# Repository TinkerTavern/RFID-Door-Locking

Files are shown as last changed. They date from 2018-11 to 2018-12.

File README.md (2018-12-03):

# RFID-Door-Locking
## Year 1 Semester 1 Coursework 2: An RFID Door lock with facial detection

This coursework involved only one main task: To create a program that uses 2 Arduinos communicating
together in some way.

With this, we decided to create an RFID door locking system, that uses facial detection to trigger.

This works by:
1) Using a python program, linked to OpenCV to detect a face in a live feed of a webcam
2) Once a face is detected, a serial command is sent to the master Arduino, to start the code
3) When the code starts, a 30 second timer starts, and the user is asked to scan a valid RFID tag
4) If the user scans a valid tag, the user is then asked to answer a question (the answer being 00101010, 42 in binary)
5) If they enter that correctly and in sufficient time, then the "door" is unlocked, and a noise is made

The RFID tags and question answers are sent to a slave Arduino, which then checks to see if it's valid, and sends that back
If the user enters 3 incorrect passwords; scans an invalid card 3 times; or doesn't finish the tasks in time, the user will be
locked out and an alarm will go off.

All of the information is shown on a small TFT screen, controlled by the master Arduino
This information includes the timer and the text telling the user what to do

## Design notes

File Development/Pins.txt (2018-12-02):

0/1- USB Comms (reserved)
2/3- BT Comms
4-
5- Buzzer
6-8- TFT Screen
9-13- RFID Reader
A0-A2- Buttons
A4/A5- LED's

ICSP Pins
3/4- Screen

~ Red: 3/5V
~ Black: GND
~ Orange: RX/TX Comms
~ Blue: RFID Scanner
~ Yellow: MSI
~ Gray: MSO
~ Green: Screen
~ White: Piezo, Buttons and Bubble Boi

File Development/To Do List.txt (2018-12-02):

## To Do List ##

~ Change question to "What is the answer to the universe" (42 in binary); J DONE
~ Get a timer working (possibly show on the screen); J DONE
~ Get face detection to link to arduino; T DONE
~ Reset program on win; TJ DONE
~ Get bubble boi to work; T 
~ Function for LCD Screen output (removing duplicate code); J DONE? Could be better
~ Clean code; TJ
~ Add new mode to slave for question mode; J DONE
~ Make the master play a tune when door unlocked; T DONE
~ Make an alarm when timer runs out/incorrect entry; T DONE
~ Fix the button bouncing issues (boolean); J

~ Documentation;
~ Video;

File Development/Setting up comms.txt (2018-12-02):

Slave Arduino:
	To start connect
	5v ---> EN
	Rx ---> Rx
	Tx ---> Tx
	Send empty sketch to arduino (with Rx/Tx disconnected)
	As arduino starts up hold button on side of arduino
	Open Serial monitor at 38400 Baud and both NL & CR
Commands Sent:
	AT + UART --- this should show 38400
	AT + ROLE? --- this should show 0
	AT + ADDR? -- should give an address, save this for master

Master Arduino:
	To start connect
	5v ---> EN
	Rx ---> Rx
	Tx ---> Tx
	Send empty sketch to arduino (with Rx/Tx disconnected)
	As arduino starts up hold button on side of arduino
	Open Serial monitor at 38400 Baud and both NL & CR
Commands Sent:
	AT + UART --- this should show 38400
	AT + ROLE = 1 --- this should show "ok" and will set it to master
	AT + CMODE = 0 --- connect mode to fixed address
	AT + BIND = Address --- address seperated by commas not colons
				this is attaching the address to be connected to 

now when done disconnect 5v ---> EN 
			 connect RX and TX on module to pins you want on arduino

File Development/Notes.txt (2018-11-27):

Face Detection:
- 

+ A little faster (if needed)

Arduino-PC Comms:
- Read the actual data
- 

+ If we want, we can use HM 10 modules for extra comms with PC and phones
+

LED Matrix:
- Points to current focus (camera, tag or questions)
- If wrong, X mark, happy face if right

Documentation:
- Write about the sections you do AS YOU GO ALONG (but not in big detail) 
- References
-

Features:
- Face Detection
- Arduino-PC Comms
- Arduino-Arduino comms
- RFID Scanner
- LED Matrix
- Screen and buttons (maybe numpad)
- Speakers (synchronised)

Potential problems:
- Not enough pins
- Comms issues

Questions:
- What happens when the user enters a wrong answer or wrong tag.

Camera first
Then Tag
Then Question

We thouhgt we wouldn't have enough pins for our project, however some research (LINK), shows that the analogue in pins can in fact be used
We thought about using a shift register for other components.. thoughts later

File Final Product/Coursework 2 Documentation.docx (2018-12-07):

# Overview

Our project is a prototype for a high-security RFID door lock system that would be used in an area where multi factor authentication (e.g. government building). The program involves 2 Arduinos, a master and a slave. The master runs all the hardware components, including an RFID scanner, 2 buttons, a piezo speaker, a screen and a servo (to represent the door lock mechanism). The slave Arduino controls the security and has no hardware components. They’re both connected through Bluetooth serial, using HC-05 modules.

# Software

Face Detection: For the prototype, we’ve decided to go with facial detection, as it is significantly easier to implement, given the time constraints. In order to do this, we’ve created a python 3 program using a library called Open CV. This has inbuilt face detection algorithms. Of which we’ve decided to use the HAAR algorithm (Cascade).

PC-Arduino Comms: In order for the face detection to be linked with the Arduino, the python program must send a serial command to the master Arduino. This is done using a library called PySerial, and allows for the main program to be run only when a face has been detected for long enough

Master Program: The master program controls the majority of the components used in the system, including the RFID scanner, the TFT screen, the buttons, and the “door lock”, which is a servo in the prototype.

Master-Slave Comms: The master must communicate with the slave every time an rfid tag is scanned, or a password is entered. This is then checked with the correct/expected output(s), and another signal is sent back to the master.

Slave Program: The slave is mostly checking the expected outputs against the actual outputs. However, it’s also in charge of controlling the bubble machine whenever the timer runs out, or they get 3 passwords or RFID tags wrong

# Hardware

PC: The computer simply needs python 3.X with the previously mentioned libraries installed, as well as a webcam, and a spare USB port to plug the master in to. In a final version of this program, the PC-Arduino coms might be done through Bluetooth/another wireless communication protocol

Master: The master contains: An [Name] RFID receiver; a TFT screen; 2 buttons; a piezo speaker; a 9g servo and a HC-05 Bluetooth module in master mode. In a final version of this system, a pin pad would replace the buttons, so the pin can be harder to crack (> 256 options)

Slave: The slave contains: A [Name] relay connected to a bubble machine and a HC-05 Bluetooth module in slave mode. In a final version of this system, the bubble machine would be replaced with something higher security, such as a taser

Communications: We decided to go for a Bluetooth serial connection between the two Arduinos, because in the final version of this system, one of the modules would be in a different area. This would probably use WiFi/ethernet, however using this for our prototype would have been a challenge due to issues regarding the network used on campus. Using Bluetooth also made development of the project easier, as the Arduinos didn’t need to be right next to each other while testing and developing features

# Difficulties

PC-Arduino Coms: The main issue we had here was involving the fact that we couldn’t see the serial display for the master Arduino while the python program was communicating with it.

Master-Slave Coms: The main issue we had when it came to getting the Arduinos to communicate was setting up and connecting the two HC-05 modules together. Once they were together, the process of using them was the same as typical serial if they were wired together

Connecting the TFT Screen and RFID Reader Simultaniously: When we were trying to connect the two devices to the master at the slave time, we noticed that some of the pins on each device can’t be reassigned using code (MOSI, MISO and [Insert]) pins were preassigned and need to be used in order for the device to function. After some research, we found out that the 6 female [NAME] pins on the Arduino board can be used as secondary pins for such features. Therefore all we needed to do was plug them into there.

Fritzing Schematic: While making the schematic, we ended up not having all of the components we used in our system available for use. On top of this, the 6 female [NAME] pins that we had to use weren’t available on the Arduino schematic on the program. This meant building the schematic was more challenging, as we had to “build” our own schematics for each of the new components

Connecting the Bubble Machine: Due to the bubble machine being an off the shelf product, it wasn’t inherently designed to work with the Arduino. This led to power issues whenever the device was plugged in for controlling, due to the machine containing 4 AA batteries (for 6v power), and a button, which was removed for the process of wiring it up. The solution to this was using a relay, and connecting the machine along the closed portion of the switch, with the coil being controlled by a digital out pin. This meant it could then be programmed simply by using digitalWrite(X,HIGH/LOW), just like an LED.

Inherent Issues: Due to time constraints, as well as the limitation of people/knowledge, we wouldn’t have been able to complete the full project. However, we made a working prototype that represents the goal of the system

# Conclusion

# Appendix

# Contributions

Hardware: Jake Misfud – 50%; Tom Lancaster – 50%.

Software: Jake Misfud – 50%; Tom Lancaster – 50%.

Research: Jake Misfud – 50%; Tom Lancaster – 50%.

Report: Jake Misfud – 50%; Tom Lancaster – 50%.

# Images

Schematic Here

# References

https://www.youtube.com/watch?v=Q8QlNuTUe4M

https://realpython.com/face-detection-in-python-using-a-webcam/

https://docs.opencv.org/3.4.3/d7/d8b/tutorial_py_face_detection.html

https://www.arduino.cc/en/Tutorial/AnalogInputPins

https://www.arduino.cc/en/Guide/TFT#toc9#

https://www.arduino.cc/en/Reference/SPI

https://playground.arduino.cc/Main/PinChangeInterrupt

https://www.forward.com.au/pfod/ArduinoProgramming/TimingDelaysInArduino.html

Jake Misfud and Tom Lancaster

CM10194 – Computer Systems Architecture: Coursework

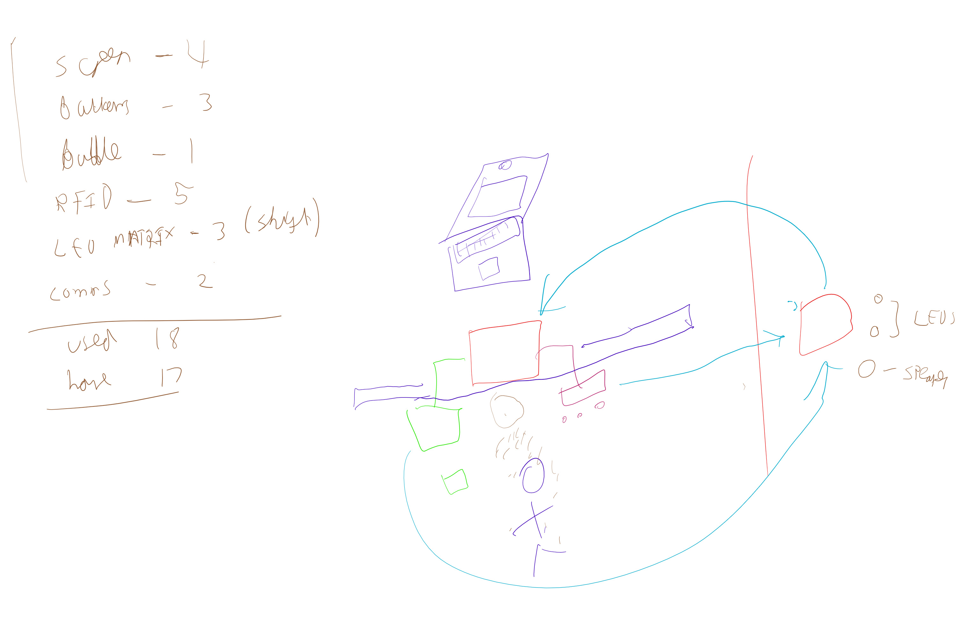
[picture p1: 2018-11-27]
Development/Rough Drawing.png

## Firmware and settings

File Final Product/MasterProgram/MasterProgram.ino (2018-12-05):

//importing servo library
#include <Servo.h>
//initializing servo
Servo doorLock;
int pos = 0;

#include <millisDelay.h>
// RFID Libraries
#include <MFRC522.h>
// TFT Screen Libraries
#include <SPI.h>
#include <TFT.h>
// Bluetooth library (Software serial)
#include <SoftwareSerial.h>
// Initializing bluetooth connection
SoftwareSerial mySerial(4, 5); // RX, TX Pins for the HC-05 modules
// TFT Screen pins, configured to be different for compatability
#define cs 8
#define dc 7
#define rst 6
// RFID Pins, not changed
#define RST_PIN 9
#define SS_PIN 10
int answerButton1 = 2;
int answerButton2 = 3;
String RFIDValid = "f";
String binaryAnswer = "";

TFT TFTscreen = TFT(cs, dc, rst);

MFRC522 rfid(SS_PIN, RST_PIN);   // Create MFRC522 instance.

MFRC522::MIFARE_Key key;

millisDelay timer;

// Init array that will store new NUID
byte nuidPICC[4];

char sensorPrintout[13];
bool faceDetected = false;
String timeRemaining;

// A boolean value to store whether the buttons have been pressed
bool buttonsPressed = true; //starts as true as we dont want the user to use buttons at the start

// Setup function initializing variables and starting connections.
void setup() {
  TFTscreen.begin();
  doorLock.attach(A5);
  mySerial.begin(38400);
  Serial.begin(9600); // Initialize serial communications with the PC
  while (!Serial);    // Do nothing if no serial port is opened (added for Arduinos based on ATMEGA32U4)
  SPI.begin();        // Init SPI bus
  rfid.PCD_Init(); // Init MFRC522
//    for (byte i = 0; i < 6; i++) {
//      key.keyByte[i] = 0xFF;
//    }
  attachInterrupt(0, answer1, FALLING); // Specifying which interrupt pins correspond to which pin, and specifying the ISRs
  attachInterrupt(1, answer2, FALLING);

  pinMode(answerButton1, INPUT); // Set player buttons as inputs
  pinMode(answerButton2, INPUT);

  TFTscreen.background(255, 0, 0);
  TFTscreen.stroke(255, 255, 255);
  TFTscreen.text("Waiting for face", 5, 40); // Replaces the text with an empty string
}

// Main function which will be looped through
void loop() {
  // Checking if a face has been detected from the slave arduino
  if (!faceDetected) {
    String newString;
    newString = "True";
    //if (Serial.available()) {
      while (Serial.available()) {
        delay(10);  // Small delay to allow input buffer to fill
        char c = Serial.read();  // Gets one byte from serial buffer
        newString += c;
      } // Makes the string readString
      // If a face has been detected, start the timer
      if (newString.length() > 0) {
        if (newString == "True") {
          tone(A0, 3000, 500); // Correct tag noise
         
          faceDetected = true;
          TFTscreen.background(255, 0, 0);
          TFTscreen.stroke(255, 255, 255);
          TFTscreen.text("Please scan RFID card", 5, 40); // Replaces the text with an empty string
          if (!timer.isRunning()) timer.start(30000);
          if (timer.isRunning()) timer.restart();

          updateTimer();
        }
   //   }
    }
  }
  // Check the timer to see if it has run out, if not then update said timer.
  else {
    checkTimer();
    updateTimer();
    // If they have not scanned a correct RDIF tag
    if (RFIDValid == "f") {
      String sensorVal;
      // Look for new cards
      if (! rfid.PICC_IsNewCardPresent())
        return;

      // Verify if the NUID has been readed
      if ( ! rfid.PICC_ReadCardSerial())
        return;

//            MFRC522::PICC_Type piccType = rfid.PICC_GetType(rfid.uid.sak);
//      
//            // Check is the PICC of Classic MIFARE type
//            if (piccType != MFRC522::PICC_TYPE_MIFARE_MINI &&
//                piccType != MFRC522::PICC_TYPE_MIFARE_1K &&
//                piccType != MFRC522::PICC_TYPE_MIFARE_4K) {
//              return;
//            }

      // Store NUID into nuidPICC array
      for (byte i = 0; i < 4; i++) {
        nuidPICC[i] = rfid.uid.uidByte[i];
      }

      // TFTscreen.stroke(255,0,0); // Clears the previous text
      // TFTscreen.text(sensorPrintout, 10, 70); // Replaces the text with an empty string

      sensorVal = byteToStringArray(rfid.uid.uidByte, rfid.uid.size);
      // Halt PICC
      rfid.PICC_HaltA();
      // Stop encryption on PCD
      rfid.PCD_StopCrypto1();

      sensorVal.toCharArray(sensorPrintout, 13); // Converts the string to a char array for display
      mySerial.write(sensorPrintout); // Sends the RFID tag for verification
      delay(200); // Delay to ensure the slave's response is finished before checking
      RFIDValid = recieveCommand();

      // If they have scanned a correct RFID tag then we need to swap to question mode
      if (RFIDValid == "t") {
        updateScreen("Access Granted", 15, 5, 40);
        tone(A0, 3000, 500); // Correct tag noise
        delay(1000);
        checkTimer(); // Checking if the time is up
       updateScreen("What is the answer ", 21 , 5, 20);
          TFTscreen.text("to the universe?", 5, 40);
          TFTscreen.text("1", 50, 60); // Replaces the text with an empty string
          TFTscreen.text("0", 50, 80); // Replaces the text with an empty string
        buttonsPressed = false;

      }
      else if (RFIDValid == "r") {
        // If the return was "r" restart the program after the alarm is turned on
        // As there have been 3 incorrect rfid scans
        startAlarm();
      }
      else {
        // Else, if the RFID was not valid then, display access denied and play an alarm
        updateScreen("Access Denied", 15, 5, 40);
        tone(A0, 100, 500); // Incorrect tag
      }
    }
    // If the RFID tag has been answered as correct, then check the question answer
    else {
      delay(10);
      // If the answer is of length 8 then it is a full answer and needs to be evaluated
      if (binaryAnswer.length() == 8) {
        //      String Answer="";

        char Answer[8];
        // Loops through the answer and adds it to a char array
        // To be writted to the slave arduino for checking
        for (int i = 0 ; i < 8; i++) {
          Answer[i] = binaryAnswer.charAt(i);
          Answer[i + 1] = '\0';
        }
        Serial.println(Answer);
        mySerial.write(Answer);
        // A delay of 300 to allow the slave arduino to recieve,process and send a response
        delay(300);
      }
      // If there is a message from the slave
      if (mySerial.available()) {
        String result = recieveCommand();
        binaryAnswer = "";
        // If the slave returned true then the "door" will be opened
        // A nice tune will also be played and the program will restart after some time
        if (result == "t") {
          for (pos = 0; pos <= 180; pos += 1) { // goes from 0 degrees to 180 degrees
            doorLock.write(pos);              // tell servo to go to position in variable 'pos'
            delay(2);                       // waits 15ms for the servo to reach the position
          }
          updateScreen("Door Opened", 12, 5 , 40);
          delay(500);
          tone(A0, 300, 500);
          delay(200);
          tone(A0, 900, 500);
          delay(200);
          tone(A0, 1200, 500);
          restartProgram();
          for (pos = 180; pos >= 0; pos -= 1) { // goes from 180 degrees to 0 degrees
            doorLock.write(pos);              // tell servo to go to position in variable 'pos'
            delay(2);                       // waits 15ms for the servo to reach the position
          }
        }
        else if (result == "r") {
          // If the return was "r" restart the program after the alarm is turned on
          // As there have been 3 incorrect question answers
          startAlarm();
        }
        else {
          // If the slave returns anything other then true
          // output that the answer is wrong and reset the questions
          delay(1000);
          binaryAnswer = "";
          updateScreen("Wrong Answer! Try Again", 25, 5, 40);
          delay(1000);
          // Re-writing the screen
          updateScreen("What is the answer ", 21 , 5, 20);
          TFTscreen.text("to the universe?", 50, 40);
          TFTscreen.text("1", 50, 60); // Replaces the text with an empty string
          TFTscreen.text("0", 50, 80); // Replaces the text with an empty string
          binaryAnswer = "";
        }


      }
      // Turn the buttons back on

      if (faceDetected == true) {
        buttonsPressed = false;
      }
    }
  }
}


// This function will take the input from system.read and turn it int oa string array
String byteToStringArray(byte *buffer, byte bufferSize) {
  String arr[bufferSize];
  // Loop through for each integer value and store it in a new array
  for (byte i = 0; i < bufferSize; i++) {
    arr[i] = String(buffer[i], HEX);
  }
  // Pass the new array to the intArrayToString function which will return a string
  String str = intArrayToString(arr, bufferSize);
  return str;
}

// This is used by the above function, to turn a string into an integer
String intArrayToString(String *intArray, byte bufferSize) {
  // For each Value in the array we loop through and add this to a new string which we then return
  String fullString;
  for (int j = 0; j < bufferSize; j++) {
    fullString.concat(intArray[j]);
    fullString.concat(" ");
  }
  return fullString;
}


void answer1() { // ISR for the answer 1 button
  if (buttonsPressed == false) {
    binaryAnswer += "1";
    buttonsPressed = true;
  }
}

void answer2() { // ISR for the answer 2 button
  if (buttonsPressed == false) {
    binaryAnswer += "0";
    buttonsPressed = true;
  }
}

// Here we have a function used to recieve information from the slave arduino
String recieveCommand() {
  String command;
  delay(100);
  // If the connection is available (there is data on the connection)
  if (mySerial.available()) {
    char c = mySerial.read();  // Gets one byte from serial buffer
    command += c; // Adds byte to a string
  }
  // If the string is not null return the string
  if (command.length() > 0) {

    return command; // Returns the string
  }
  else return "f"; // Returns f if nothing found
}

// Update the timer function, this updates the timer on the led screen
void updateTimer() {
  char buff[5];

  int timeBuffer = timer.remaining() % 1000;
  if (timeBuffer < 150) {
    TFTscreen.fill(255, 0, 0);
    TFTscreen.stroke(255, 0, 0);
    TFTscreen.rect(0, 0, TFTscreen.width(), 20);
    timeRemaining = String(timer.remaining() / 1000);
    timeRemaining.toCharArray(buff, 5);
    TFTscreen.setTextSize(2);
    TFTscreen.stroke(255, 255, 255);
    TFTscreen.text(buff, 0, 0);
    TFTscreen.setTextSize(1);
  }

}

// Function to check if the time is up
void checkTimer() {
  // Boolean value to store if the timer is up
  bool timerCheck = timer.isFinished();
  // If the timer is up, or either the RFID or the question have been done wrong 3 times then
  if (timerCheck) {
    // Repeat an alarm
    startAlarm();
  }
}

// Triggers the alarm by showing text on the screen and triggering the piezo speaker
void startAlarm() {
  // Update the screen
  mySerial.write("b");
  updateScreen("INTRUDER ALERT!!!!!!", 22, 5, 20);
  for (int i = 0; i < 10; i++) {
    tone(A0, 2000, 500);
    delay(200);
    tone(A0, 3000, 500);
    delay(200);
  }
  // Restart the program
  restartProgram();
}

// This is the function for updating the text on the screen
// It takes as input the text itself, length, x and y
void updateScreen(String text, int textLen, int x, int y) {
  TFTscreen.background(255, 0, 0);
  TFTscreen.stroke(255, 255, 255); // Clears the previous text
  char buf[textLen];
  text.toCharArray(buf, textLen);
  TFTscreen.text(buf, x, y);
}

// This function restarts the program at the end
// It does so by resetting all variables and the screen and waiting for 5 seconds
void restartProgram() {
  RFIDValid = "f";
  binaryAnswer = "";
  faceDetected = false;
  buttonsPressed = true;
  delay(5000);
  TFTscreen.background(255, 0, 0);
  TFTscreen.stroke(255, 255, 255);
  TFTscreen.text("Waiting for face", 5, 40); // Replaces the text with an empty string
}

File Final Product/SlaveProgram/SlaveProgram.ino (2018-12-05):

/* Slave Arduino:
  To start connect
  5v ---> EN
  Rx ---> Rx
  Tx ---> Tx
  Send empty sketch to arduino (with Rx/Tx disconnected)
  As arduino starts up hold button on side of arduino
  Open Serial monitor at 38400 Baud and both NL & CR
Commands Sent:
  AT + UART --- this should show 38400
  AT + ROLE? --- this should show 0
  AT + ADDR? -- should give an address, save this for master

Master Arduino:
  To start connect
  5v ---> EN
  Rx ---> Rx
  Tx ---> Tx
  Send empty sketch to arduino (with Rx/Tx disconnected)
  As arduino starts up hold button on side of arduino
  Open Serial monitor at 38400 Baud and both NL & CR
Commands Sent:
  AT + UART --- this should show 38400
  AT + ROLE = 1 --- this should show "ok" and will set it to master
  AT + CMODE = 0 --- connect mode to fixed address
  AT + BIND = Address --- address seperated by commas not colons
        this is attaching the address to be connected to 

now when done disconnect 5v ---> EN 
       connect RX and TX on module to pins you want on arduino */

       
// Including the library for soft serial
#include <SoftwareSerial.h>
SoftwareSerial mySerial(2, 3); // RX, TX Pins for the HC-05 modules
// Initializing variables
String input; // To store the input
String validIDs[2] = {"1d 53 fe 9c ","bd a5 0 9d "}; // The valid RDIF UIDs
int RFIDWrong; // How many times the RFID has been scanned wrong
int questionWrong; // Jow many times the question has been answered wrong

void setup() {
  // Establish connections
  Serial.begin(9600);
  mySerial.begin(38400);
  pinMode(5, OUTPUT);
}

void loop() {
  input = ""; // Clears variable for new input
  delay(10);
  //if there is data
  if (mySerial.available()) {
    // While data is comming, add the data to the input string
    while (mySerial.available()) {
      delay(10);  // Small delay to allow input buffer to fill

      char c = mySerial.read();  // Gets one byte from serial buffer
      input += c;
    } // Makes the string readString
  Serial.println(input);
   // If the input length > 9 then it is for the RFID. therefor check the RDIF UID
    if (input == "b" ){
      activateBubbleMachine();
    }
    if (input.length() > 9) {
      testUID(input);
    }

    // If it is not over 9 then it is for the question
    else{
      if (input == "00101010"){ // Checks if the input is 42 in binary
        mySerial.write("t"); // Writes true
        Serial.println("t");
      }
      else{
        questionWrong ++; // Increments the amount of wrong questions
        returnFalse();
      }
    }
  }
}

// This funciton will test the inputted UID against the ones stored
void testUID(String ID) {
  bool valid = false;
  // For each correct ID compare them to the given ID
  for (String testID: validIDs) {
    if (ID == testID) {
      valid = true;
    }
  }
  // If it is valid then write true
  if (valid) {
            Serial.println("t");

    mySerial.write("t"); 
  }
  else {
    // If it is not increment the amount of wrong RFIDs , and return 
   RFIDWrong ++;
   returnFalse();
   }
}


void returnFalse(){
  if ((RFIDWrong > 2) || (questionWrong > 2)){
    RFIDWrong = 0;
    questionWrong = 0;
   
    mySerial.write("r");
            Serial.println("r");
  }
  else{
    mySerial.write("f");
            Serial.println("f");
  }
}


void activateBubbleMachine() {
  digitalWrite(5, HIGH);
  delay(7000);
  digitalWrite(5, LOW);
}

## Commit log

2018-11-26 Working Facial Detection Prototype
    + Added python file for face detection with communications to arduino
    + Added .ino file for a blink program that blinks when the computer tells it to
2018-11-28 Working Validation!
    + Added Pins.txt to show the pin layout
    + Added UID validation on the RFID
    ~ Need to get a more reliable comms between arduino and PC
2018-11-29 Comms working
    +softSerial coms
    +added libraries to folder
    ⁓output of screen
    #make a function for the screen as lots of repeated code there
2018-11-29 Added slave code
    +slave ino file that i forgot to add
    #make it shoot bubble boi
    #pc to arduino coms
2018-11-29 Pin Changes
    # Moved ino file inside a folder
    # Changed the pins in the master program
    ~ Attach pin interrupts
2018-11-29 Buttons!
    +buttons to answer questions
2018-11-29 An Attempt at Validation Comms
    + Added recieveCommand method in master program
    + Added testUID method in slave program
    ~ Need to fix weird bug where the first valid UID always returns " ", instead of "t"
    [Screen_RFID.ino, SlaveTest.ino]
2018-11-29 BugFix and To Do List
    # Fixed all the bugs
    ~ Change question to "What is the answer to the universe" (42 in binary)
    ~ Get a timer working (possibly show on the screen)
    ~ Get face detection to link to arduino
    ~ Reset program on win
    [Arduino Comms.py, Screen_RFID.ino, SlaveTest.ino]
2018-11-29 PC-Arduino Comms Working!!
    + Added To do list
    + Working PC-Arduino Comms!
    ~ Documentation for all my stuff
2018-11-30 Question Done
    +made question work
    + maybe made face + screen nicer
    :( got stuck for ages on an error
    [Screen_RFID.ino, SlaveTest.ino]
2018-12-01 Many Changes!
    # Got a timer working!
    # Added validation, if they get it wrong 3 times it ends
    # Added an intruder alarm, and a valid alarm when door unlocked
    # Shows the timer on the screen
    ~ Need to clean the code!
    ~ Need to finish to do list
    [Arduino Comms.py, Screen_RFID.ino, SlaveTest.ino]
2018-12-02 Clean up and more coms i guess
    +cleaner code
    +many more comments
    +made slave count incorrect answers
    +fixed button interrupts
    + fixed restart function - no more setup used
    + added return "r" to slave to be restart
    +Start alarm function
    - alot of random stuff ngl
    + Comms setup text file
    -will to live
    [Screen_RFID.ino, SlaveTest.ino]
2018-12-04 Fixed (Part of) the Screen Flicker
    ~ Use a servo as a "door"
    [MasterProgram.ino]
2018-12-04 General Update
    #Changed the output to the screen
    +Noise when face detected
    +Servo open and close
    [MasterProgram.ino]
2018-12-05 Create Schematic.fzz
    +Added schematic
    [Schematic.fzz]
2018-12-05 Revert "Fixed (Part of) the Screen Flicker"
    This reverts commit 88cb16f742a639a461243d4dadd86903724f10f0.
    [MasterProgram.ino]
2018-12-05 Revert "General Update"
    This reverts commit 5a6ab1998a46241d8c638ce71bd8995cec737c0e.
    [MasterProgram.ino]
2018-12-05 Many Changes!
    # Changed timer in the python file
    # Included commenting in the slave program
    # Tweaked Documentation
    # Other stuff
